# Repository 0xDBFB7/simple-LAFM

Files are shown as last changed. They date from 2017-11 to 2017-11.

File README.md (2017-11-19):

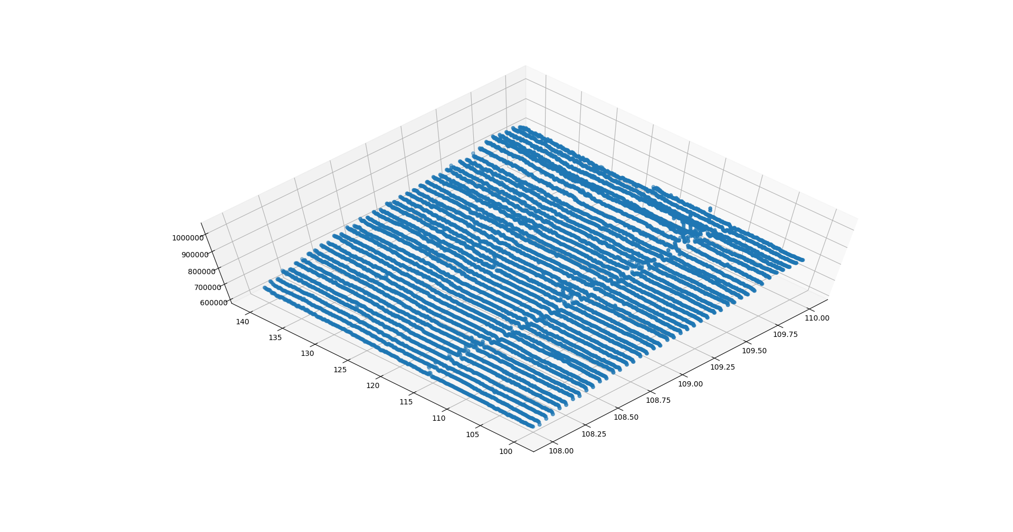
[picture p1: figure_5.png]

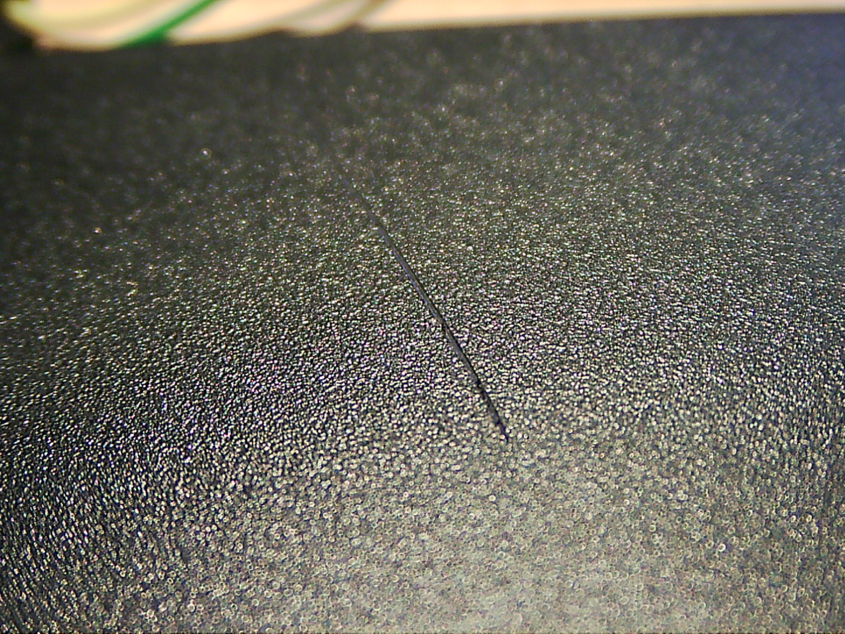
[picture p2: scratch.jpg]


I'm not entirely sure why I made this thing. I don't really have much of a use for it.

This is a very, very simple, very crude Laser Atomic Force Microscope. Sort of. In some ways it's more of a touch probe, I guess. It costs about $10 to build, using a light to frequency converter.

You can also use a CDS cell and a precision voltmeter (something that can give you at least three decimal places). Something with a 10-bit ADC would work. I used a GW-Instek GDM-8251A bench multimeter, which gives me 5 sig figs. I didn't have an LtoF converter, so this is what I used.

This is *not* a high-resolution, precision instrument. This is something I designed and built in <3 hours. It's very rough around the edges (ha). I'm chuffed to bits that the thing even works at all, really. The X and Y resolution is limited to the resolution of whatever X-Y gantry you're using.

However, it can pretty easily measure vertical deflections of around *5 microns*. With some basic improvements (a longer optical barrel, better sensor, etc), I think one could do sub micron measurements quite easily.

First, print out the afm.stl file with a 3d printer. It looks like it won't work, but actually it's quite printable.

You'll need a 5mw laser diode, and a constant voltage source for it. I ran mine at 2.3v, drawing 0.008 amps. Push the laser into the optical path like so:

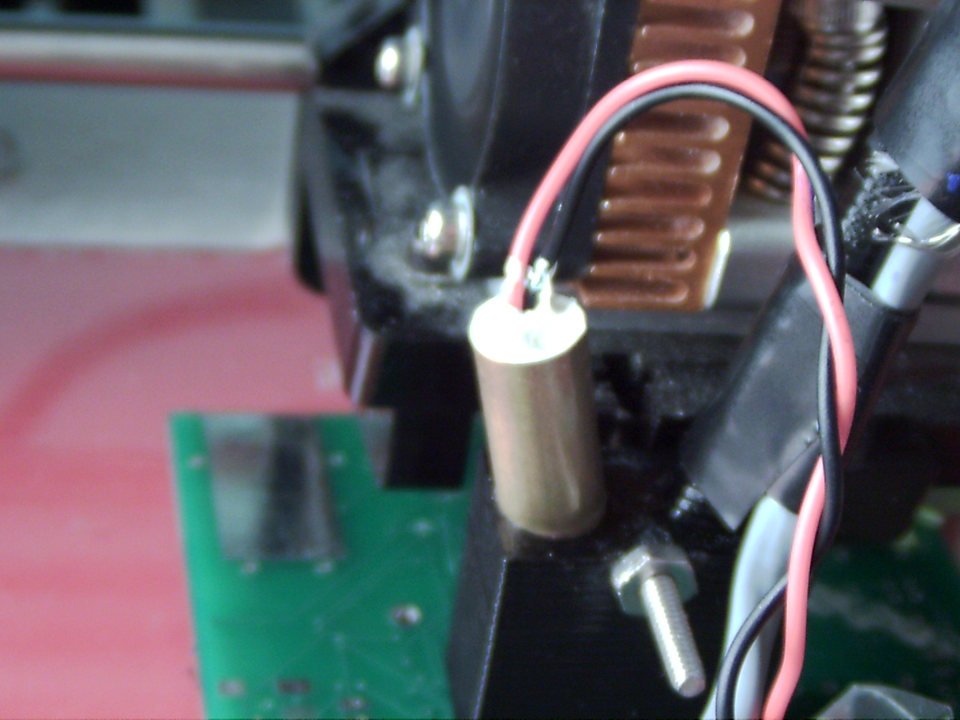
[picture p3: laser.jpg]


*WARNING* Lasers are dangerous. Be extremely careful with reflections. 

I dropped a CDS cell through the long optical barrel, and glued it in place. I made a voltage divider in order to sample a bit faster - in resistance mode my meter samples rather slowly.

Cut out a piece of standard aluminum foil in this shape:

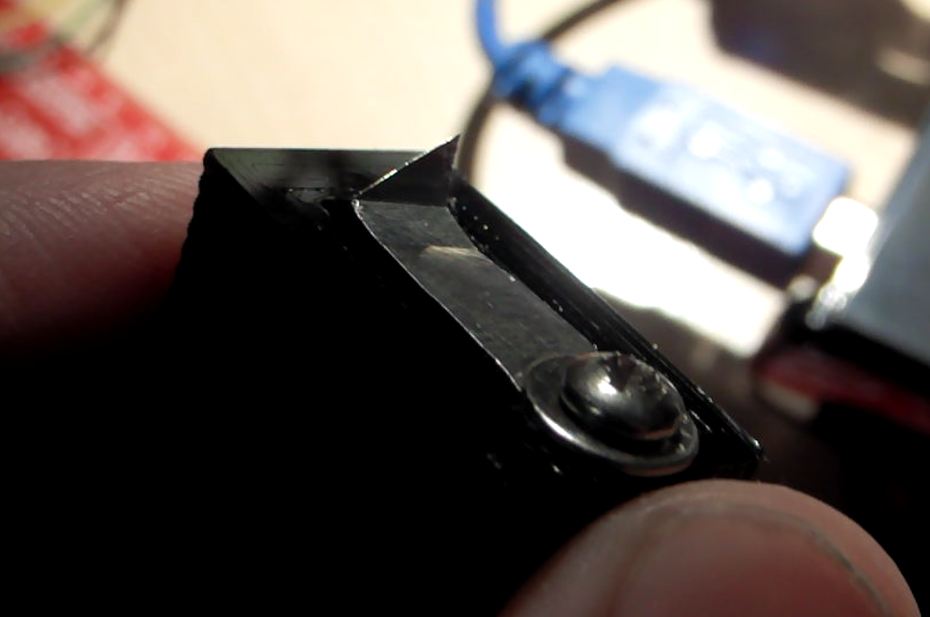
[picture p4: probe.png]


The bottom hole takes a ~10mm long 4-40 screw and washer - this affixes one end of the cantilever probe ridgidly. Ensure that the cantilever isn't touching any part of the optical enclosure.

Mount the whole thing on an X-Y-Z table/gantry/CNC machine. Atomic.py is designed to interface with RepRap 3d printers, producing a raster scan pattern. It's currently set up to interface with my multimeter, but naturally you'll have to modify that.

To take a scan, I played around with the probe a bit until I found the minimum CDS resistance. I then brought the Z down until I got the slightest perceptable change in value. I then set this value in atomic.py, and ran a test.

If you want a faster scan, substitute the CDS for a light-to-frequency converter or equivalent.

Public Domain, naturally.

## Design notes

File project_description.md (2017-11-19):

Project: Simple Atomic Force Microscope
===
Status: Completed.
-------

#### Date started: 2017-??-??
#### Date finished: 2017-??-??
#### Date written: 2017-08-13

Background:
---

##NOTE: This is not a "real" AFM. The resolution of this device is not nearly sufficient to measure very fine details.

AFM scopes use a small cantilever brought in very close proximity to a surface to be measured. The deflection of the cantilever is measured, which determines something about the surface of the material. 

Description:
---

Figured I'd give this a try - this was one of those projects that I had very little time to do research on, just watched a few videos and read one paper. I knew I wouldn't get stellar results, considering that the best resolution my 3d printer can effectively do is about 0.05 mm, and that I couldn't possibly create the fancy optics and micro-miniture probes that standard devices can.

I 3d printed a partially light-tight enclosure, with a mount for a 5mw laser diode and a CDS cell at a long boom. I cut a small 4-40 screw hole in the bottom to affix the probe cantilever. I dropped the CDS cell through and glued it in place. With the laser powered with 2.1v, drawing 0.004a, I got about 1-2 Mohm across the photoresistor. 

I cut a small cantilever probe out of a sheet of standard aluminum foil, trying to produce a sharp point.

First results seemed promising.

By moving the probe slightly by hand, I could change the resistance of the CDS cell.

I mounted the sensor to my RepRap, and wrote a bit of python that raster scans the printer, logging the CDS's resistance at each point.

I put a piece of plastic on the bed, and put a thick scratch in it.

A "surface" of sorts was created, with many small bumps. Interestingly, the surface always sloped upwards. Some thermal effect? Strange.

After greatly increasing laser power (2.3v, 0.008a), the CDS readings became much more stable.

Added a calibration routine that raises the probe every row and zeros out any drift. 

Put Adafruit's pcb ruler under the probe, set a 0.01 mm scan pattern. I could distinctly see the lands of a bga package - only 30 microns high!

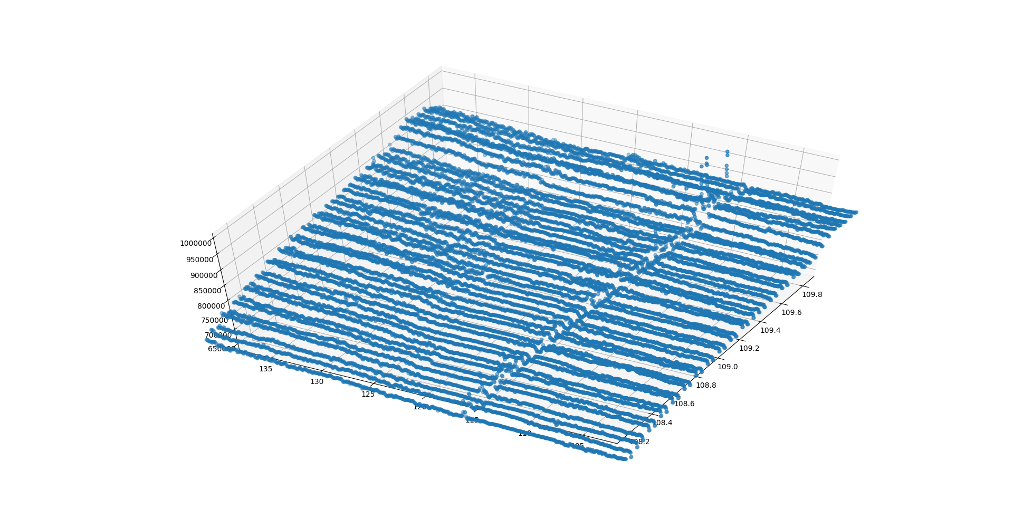
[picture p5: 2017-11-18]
figure_3.png

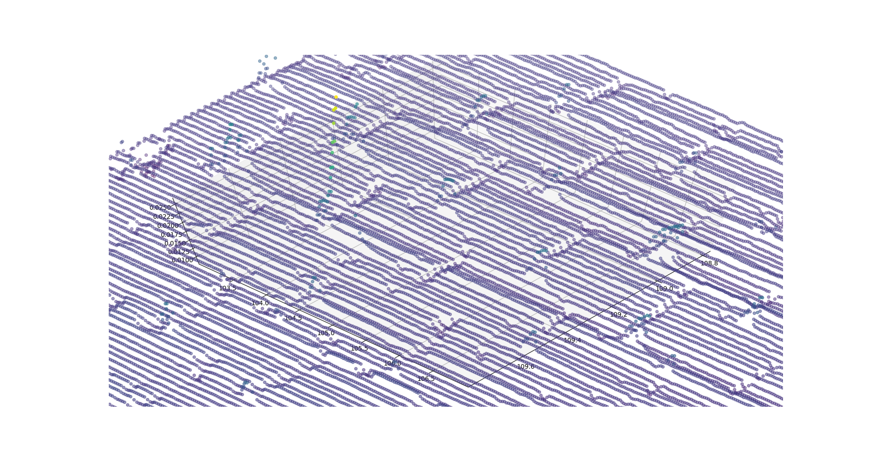
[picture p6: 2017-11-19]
figure_10.png

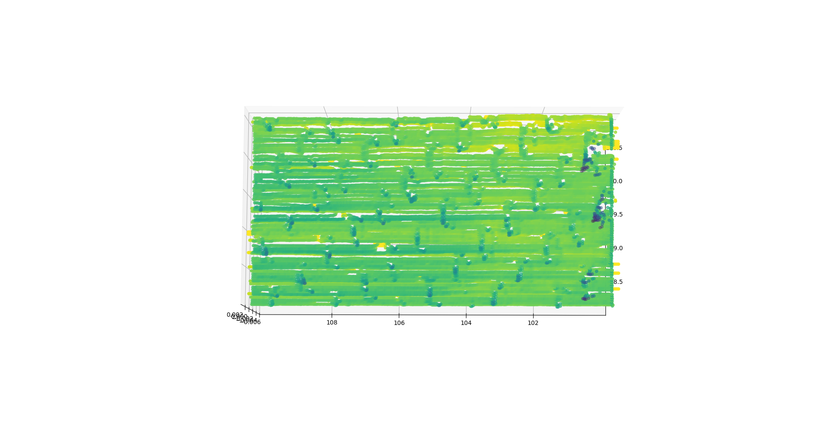
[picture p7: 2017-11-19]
figure_7.png

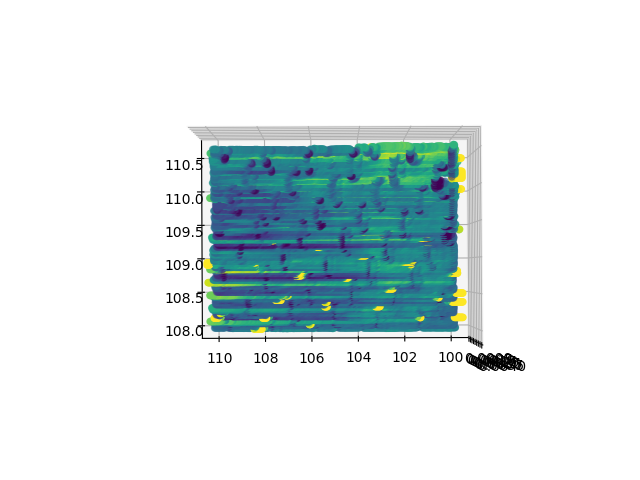
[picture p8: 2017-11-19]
figure_9.png

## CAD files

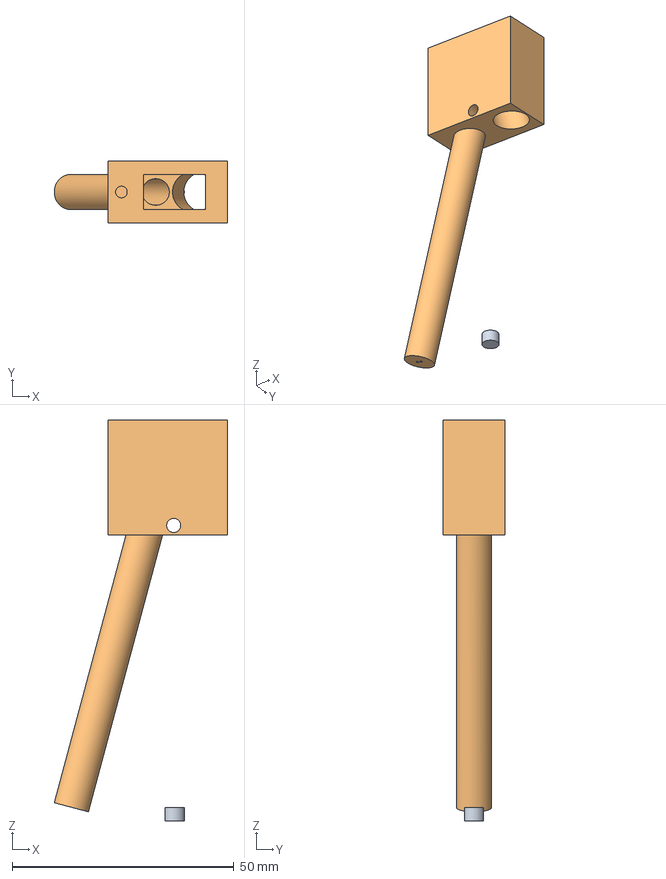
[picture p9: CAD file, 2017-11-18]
files/hardware/atomic_force_microscope.fcstd
39.2 x 14.0 x 90.5 mm
CdS

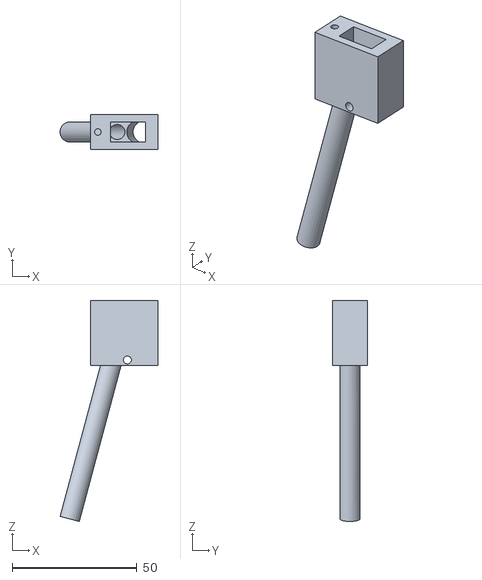
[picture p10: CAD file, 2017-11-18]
files/hardware/afm.stl
39.1 x 14.0 x 88.4

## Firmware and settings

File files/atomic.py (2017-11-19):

from time import sleep
import serial
from math import fabs
import numpy as np
psu = serial.Serial('/dev/ttyS0',115200,timeout=1)
printer = serial.Serial('/dev/ttyblackprinter',250000,timeout=None) #reprap serial port, change the baud rate to your printer's

f = open("./test.csv",'w+')

printer_x_home = 108 #initial position
printer_y_home = 100 

printer_x_step = 0.03
printer_y_step = 0.03
printer_x_travel = 10 # how far do we go on the bed?
printer_y_travel = 10

printer_z = 5.39
printer_z_high = 6.2

x_offset = 0

total_buffer = []

print('Homing Printer')
printer.write(b"G00 Z" + str(printer_z_high) + "\n")
sleep(5)
printer.write(b"G28\n")
printer.readline()
sleep(5)
print('Raising Printer')
printer.write(b"G00 Z" + str(printer_z_high) + "\n")
printer.readline()
sleep(10)
calibrate = 0
while not calibrate:
	try:
		psu.write("val1?\r\n")
		calibrate = float(psu.readline())
	except:
		pass

printer.write(b"G00 X" + str(printer_x_home) +" Y"+str(printer_y_home)+' F5000\n')
sleep(10)
for printer_x in np.arange(printer_x_home, printer_x_home+printer_x_travel, printer_x_step):
	for printer_y in np.arange(printer_y_home, printer_y_home+printer_y_travel, printer_y_step):
		printer.reset_input_buffer()
		printer.write(b"G00 X" + str(printer_x) +" Y"+str(printer_y)+'Z' + str(printer_z) +' F3000\n')
		sleep(0.7)
		current = 0
		while not current:
			try:
				psu.write("val1?\r\n")
				current = float(psu.readline())
			except:
				pass
		print(current)
		print(printer_x)
		print(printer_y)
		f.write(str(printer_x) + "," + str(printer_y) + "," + str(current-calibrate)+'\n')
	printer.write(b"G00 Z" + str(printer_z_high) + "\n")
	sleep(3)
	calibrate = 0
	while not calibrate:
		try:
			psu.write("val1?\r\n")
			calibrate = float(psu.readline())
			print('cal:')
			print(calibrate)
		except:
			pass

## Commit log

2017-11-19 Calibration routine
    [test.csv, test6.csv, test7.csv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]
2017-11-19 Re-worded title
    [test9.csv]
